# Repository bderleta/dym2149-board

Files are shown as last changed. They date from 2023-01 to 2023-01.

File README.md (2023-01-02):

# dym2149-board
Dual YM2149 synth board design using retro technology (THT elements, DIP packages)

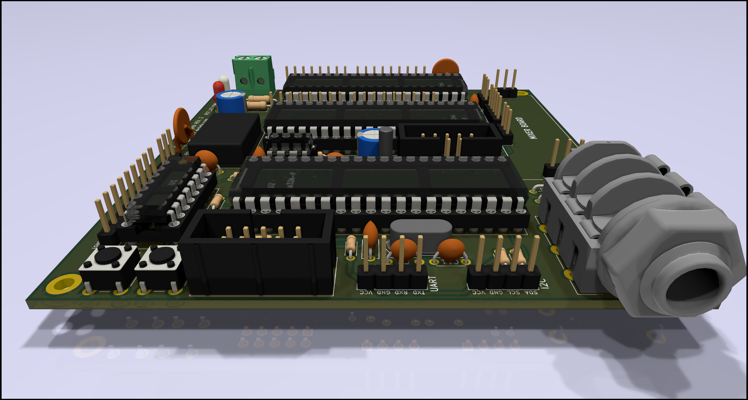
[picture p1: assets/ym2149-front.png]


An application of ATMega32 8-bit MCU in PDIP package capable of driving two of YM2149 PSG chips. [Reference firmware](https://github.com/bderleta/dym2149-firmware-ph) is just passing packets to selected PSG, but possibilities are very wide.

# Revision 2 changes

-  `U595_SRCLR` and `U595_RCLK` are swapped, to put `RCLK` to pin `OC0`, allowing to strobe `RCLK` pin from Timer0 compare output. This way the onboard shift register can be driven fully asynchronously, as `SRCLK` and `SER` are driven by SPI peripheral. Attention must be paid when SRAM/flash is used in the application.
- `YM1_BC1` and `YM1_SEL` are swapped, to put `YM1_SEL` to pin `OC1B`, allowing to switch `YM1_SEL` pin from Timer1 compare output. `YM2_SEL` is already on `OC1A` in all revisions. As `SEL` pin divides internal PSG clock by 2, in theory it should also divide an output frequency by 2, leading to sound an octave lower than before, although it has to be tested if any interesting effects can be obtained this way.
- Placement of I2C and UART ports has been slightly changed.

# Features

- ATMega32 MCU in PDIP package, clocked with external 16MHz crystal oscillator
- 10 pin ISP (KANDA) and JTAG ports 
- Two sockets for YM2149 PSG chips, independent control lines, shared data/address line
- DIP8 socket for SPI flash/RAM
- 595 shift register with 8 pin output header, controlled via SPI, for debugging/driving peripherals
- Headers for both I/O ports of each PSG
- 32768 Hz secondary oscillator for CPU Timer2
- Requires DIP8/DIP14 CXO for clocking YM chips
- Revision 1a/2 design features separate [mixer board](https://github.com/bderleta/dym2149-oric-mixer) to enable developing various output stages (different chip/channel assignments, active opamp stage, etc)

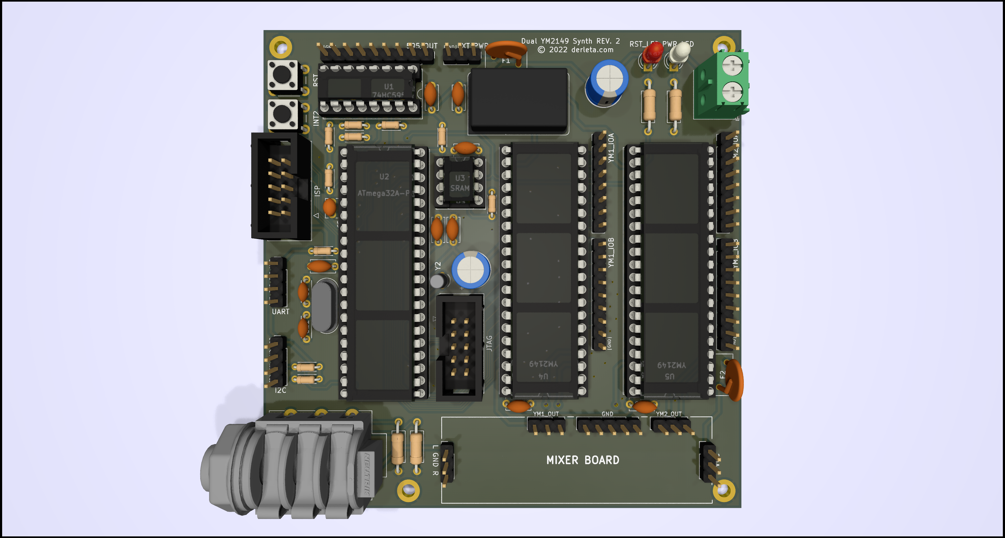
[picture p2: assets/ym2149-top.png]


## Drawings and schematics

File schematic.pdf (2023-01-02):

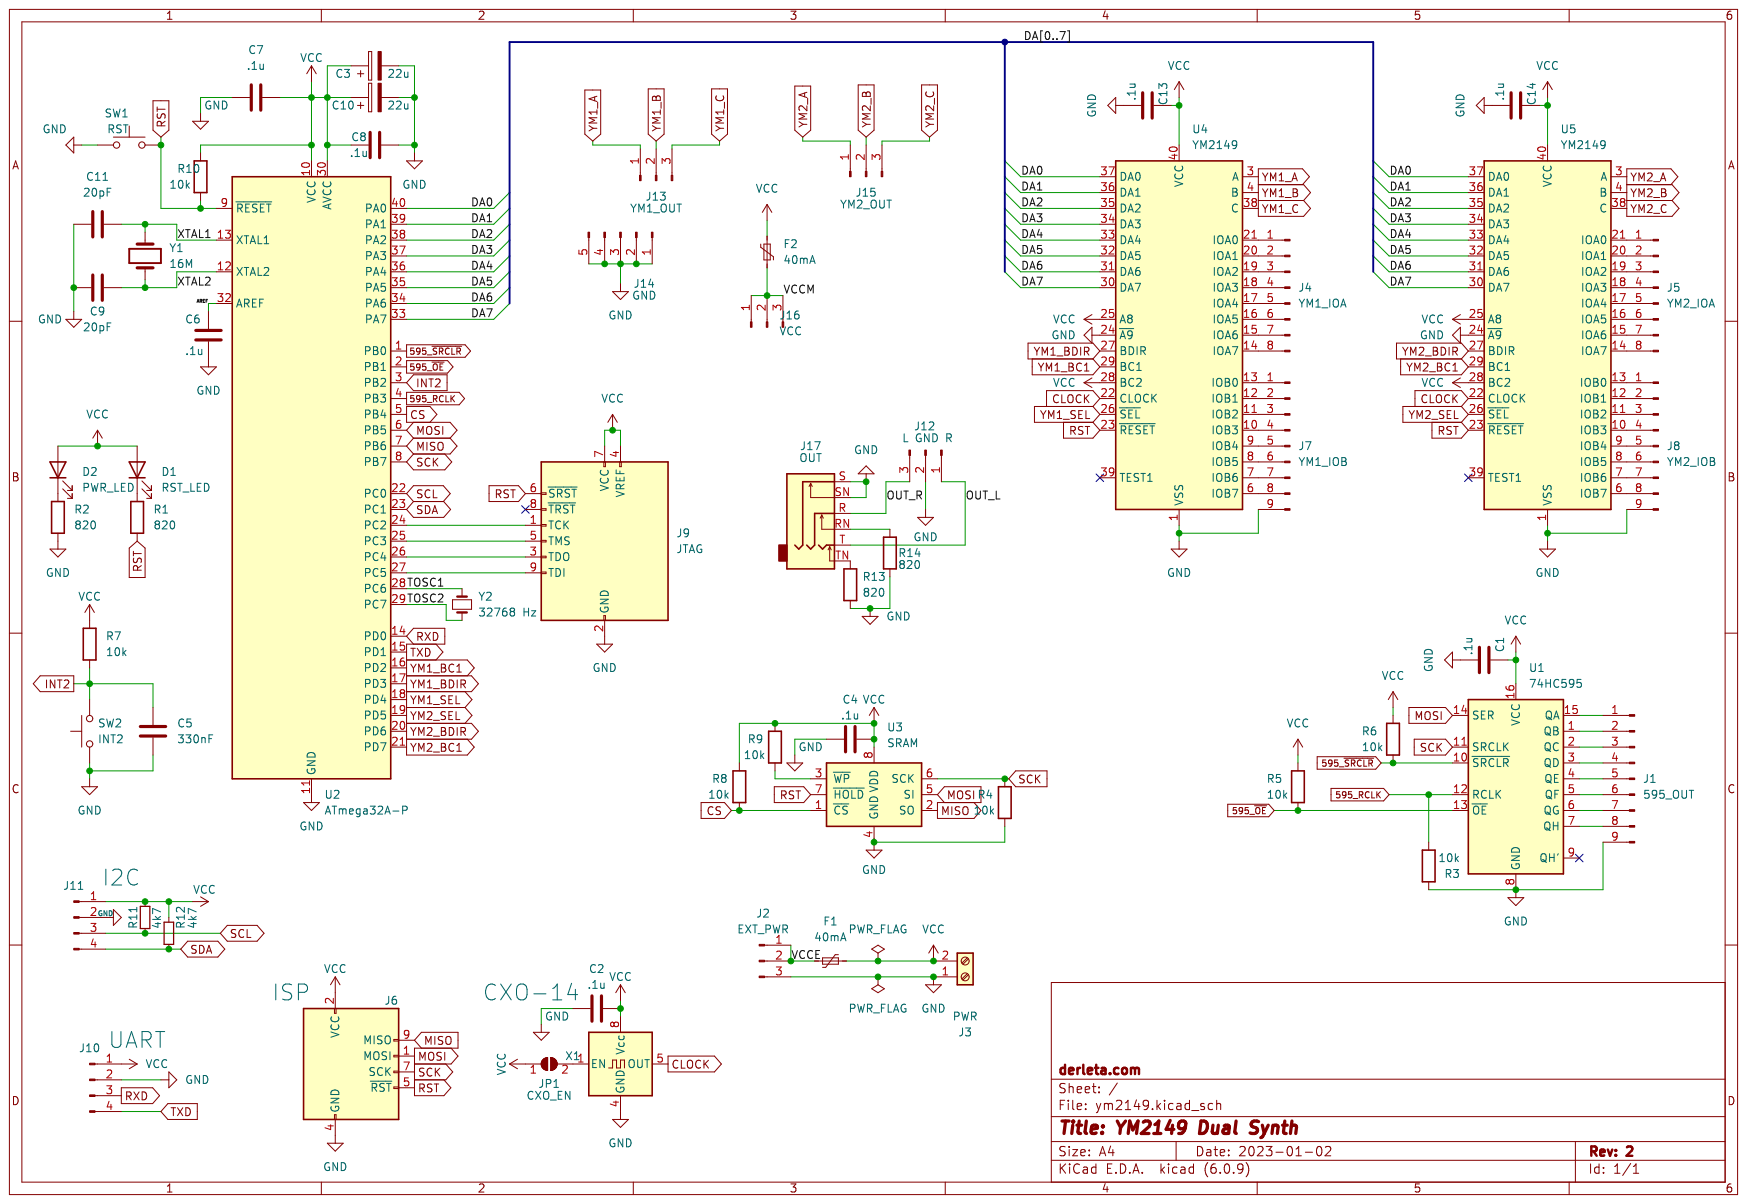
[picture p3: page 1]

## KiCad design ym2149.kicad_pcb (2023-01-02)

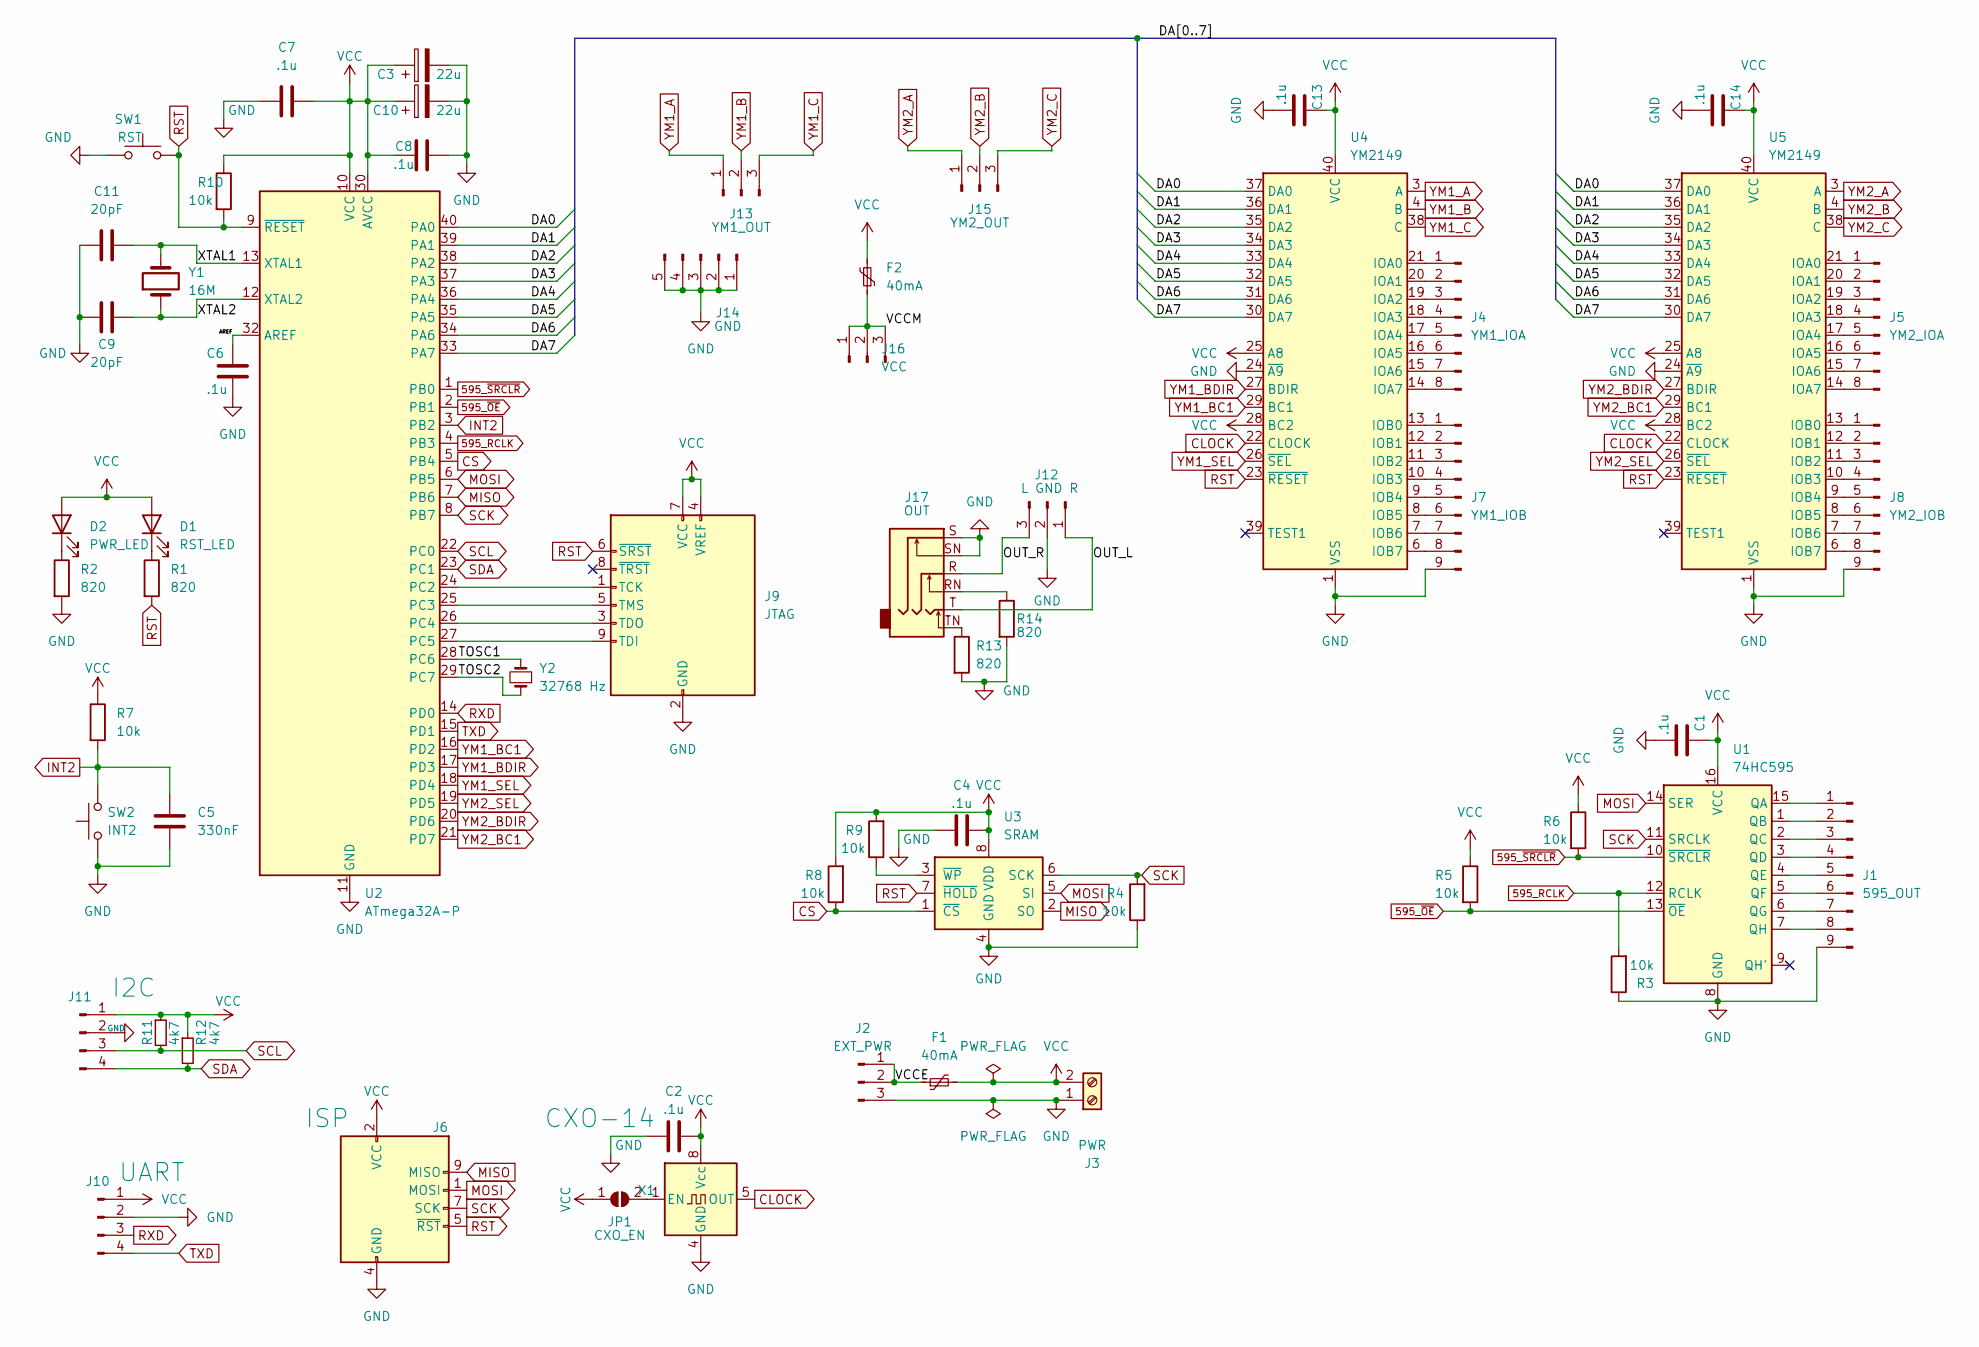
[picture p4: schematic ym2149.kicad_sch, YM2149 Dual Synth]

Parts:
C1, C2, C4, C6, C7, C8, C13, C14: .1u; C_Disc_D5.0mm_W2.5mm_P5.00mm
C3, C10: 22u; CP_Radial_D7.5mm_P2.50mm
C5: 330nF; C_Disc_D3.8mm_W2.6mm_P2.50mm
C9, C11: 20pF; C_Disc_D4.3mm_W1.9mm_P5.00mm
D1: RST_LED; LED_D3.0mm
D2: PWR_LED; LED_D3.0mm
F1, F2: 40mA; Fuse_BelFuse_0ZRE0005FF_L8.3mm_W3.8mm
J1: 595_OUT; PinHeader_1x09_P2.54mm_Vertical
J2: EXT_PWR; PinHeader_1x03_P2.54mm_Vertical
J3: PWR; TerminalBlock_Phoenix_PT-1,5-2-5.0-H_1x02_P5.00mm_Horizontal
J4: YM1_IOA; PinHeader_1x08_P2.54mm_Vertical
J5: YM2_IOA; PinHeader_1x08_P2.54mm_Vertical
J6: ISP; IDC-Header_2x05_P2.54mm_Vertical
J7: YM1_IOB; PinHeader_1x09_P2.54mm_Vertical
J8: YM2_IOB; PinHeader_1x09_P2.54mm_Vertical
J9: JTAG; IDC-Header_2x05_P2.54mm_Vertical
J10: UART; PinHeader_1x04_P2.54mm_Vertical
J11: I2C; PinHeader_1x04_P2.54mm_Vertical
J12: L GND R; PinHeader_1x03_P2.54mm_Vertical
J13: YM1_OUT; PinHeader_1x03_P2.54mm_Vertical
J14: GND; PinHeader_1x05_P2.54mm_Vertical
J15: YM2_OUT; PinHeader_1x03_P2.54mm_Vertical
J16: VCC; PinHeader_1x03_P2.54mm_Vertical
J17: OUT; Jack_6.35mm_Neutrik_NMJ6HFD2-AU_Horizontal
JP1: CXO_EN; SolderJumper-2_P1.3mm_Open_RoundedPad1.0x1.5mm
R1, R2, R13, R14: 820; R_Axial_DIN0207_L6.3mm_D2.5mm_P10.16mm_Horizontal
R3, R4, R5, R6, R7, R8, R9, R10: 10k; R_Axial_DIN0204_L3.6mm_D1.6mm_P5.08mm_Horizontal
R11, R12: 4k7; R_Axial_DIN0204_L3.6mm_D1.6mm_P5.08mm_Horizontal
SW1: RST; SW_PUSH_6mm
SW2: INT2; SW_PUSH_6mm
U1: 74HC595; DIP-16_W7.62mm_Socket
U2: ATmega32A-P; DIP-40_W15.24mm_Socket
U3: SRAM; DIP-8_W7.62mm_Socket
U4, U5: YM2149; DIP-40_W15.24mm_Socket
X1: CXO-14; CXO-14-8
Y1: 16M; Crystal_HC49-4H_Vertical
Y2: 32768 Hz; Crystal_AT310_D3.0mm_L10.0mm_Vertical

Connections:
595_RCLK: R3.2, U1.12 (RCLK), U2.4 (PB3)
595_~OE: R5.2, U1.13 (~OE), U2.2 (PB1)
595_~SRCLR: R6.2, U1.10 (~SRCLR), U2.1 (PB0)
/AREF: C6.2, U2.32 (AREF)
/DA0: U2.40 (PA0), U4.37 (DA0), U5.37 (DA0)
/DA1: U2.39 (PA1), U4.36 (DA1), U5.36 (DA1)
/DA2: U2.38 (PA2), U4.35 (DA2), U5.35 (DA2)
/DA3: U2.37 (PA3), U4.34 (DA3), U5.34 (DA3)
/DA4: U2.36 (PA4), U4.33 (DA4), U5.33 (DA4)
/DA5: U2.35 (PA5), U4.32 (DA5), U5.32 (DA5)
/DA6: U2.34 (PA6), U4.31 (DA6), U5.31 (DA6)
/DA7: U2.33 (PA7), U4.30 (DA7), U5.30 (DA7)
/OUT_L: J12.1, J17.T
/OUT_R: J12.3, J17.R
/TOSC1: U2.28 (PC6), Y2.2
/TOSC2: U2.29 (PC7), Y2.1
/VCCE: F1.1, J2.1, J2.2
/VCCM: F2.1, J16.1, J16.2, J16.3
/XTAL1: C11.2, U2.13 (XTAL1), Y1.2
/XTAL2: C9.2, U2.12 (XTAL2), Y1.1
CLOCK: U4.22 (CLOCK), U5.22 (CLOCK), X1.5 (OUT)
CS: R8.1, U2.5 (PB4), U3.1 (~CS)
GND: C1.1, C2.2, C3.2, C4.2, C5.2, C6.1, C7.2, C8.2, C9.1, C10.2, C11.1, C13.1, C14.1, J1.9, J2.3, J3.1, J6.4 (GND), J6.6 (GND), J6.8 (GND), J6.10 (GND), J7.9, J8.9, J9.2 (GND), J9.10 (GND), J10.2, J11.2, J12.2, J14.1, J14.2, J14.3, J14.4, J14.5, J17.S, J17.SN, R2.2, R3.1, R4.1, R13.2, R14.2, SW1.1, SW2.1, U1.8 (GND), U2.11 (GND), U2.31 (GND), U3.4 (GND), U4.1 (VSS), U4.24 (~A9), U5.1 (VSS), U5.24 (~A9), X1.4 (GND); also elsewhere on the board
INT2: C5.1, R7.2, SW2.2, U2.3 (PB2)
MISO: J6.9 (MISO), U2.7 (PB6), U3.2 (SO)
MOSI: J6.1 (MOSI), U1.14 (SER), U2.6 (PB5), U3.5 (SI)
unnamed: D1.1 (K), R1.1
unnamed: D2.1 (K), R2.1
unnamed: J1.1, U1.15 (QA)
unnamed: J1.2, U1.1 (QB)
unnamed: J1.3, U1.2 (QC)
unnamed: J1.4, U1.3 (QD)
unnamed: J1.5, U1.4 (QE)
unnamed: J1.6, U1.5 (QF)
unnamed: J1.7, U1.6 (QG)
unnamed: J1.8, U1.7 (QH)
unnamed: J4.1, U4.21 (IOA0)
unnamed: J4.2, U4.20 (IOA1)
unnamed: J4.3, U4.19 (IOA2)
unnamed: J4.4, U4.18 (IOA3)
unnamed: J4.5, U4.17 (IOA4)
unnamed: J4.6, U4.16 (IOA5)
unnamed: J4.7, U4.15 (IOA6)
unnamed: J4.8, U4.14 (IOA7)
unnamed: J5.1, U5.21 (IOA0)
unnamed: J5.2, U5.20 (IOA1)
unnamed: J5.3, U5.19 (IOA2)
unnamed: J5.4, U5.18 (IOA3)
unnamed: J5.5, U5.17 (IOA4)
unnamed: J5.6, U5.16 (IOA5)
unnamed: J5.7, U5.15 (IOA6)
unnamed: J5.8, U5.14 (IOA7)
unnamed: J7.1, U4.13 (IOB0)
unnamed: J7.2, U4.12 (IOB1)
unnamed: J7.3, U4.11 (IOB2)
unnamed: J7.4, U4.10 (IOB3)
unnamed: J7.5, U4.9 (IOB4)
unnamed: J7.6, U4.8 (IOB5)
unnamed: J7.7, U4.7 (IOB6)
unnamed: J7.8, U4.6 (IOB7)
unnamed: J8.1, U5.13 (IOB0)
unnamed: J8.2, U5.12 (IOB1)
unnamed: J8.3, U5.11 (IOB2)
unnamed: J8.4, U5.10 (IOB3)
unnamed: J8.5, U5.9 (IOB4)
unnamed: J8.6, U5.8 (IOB5)
unnamed: J8.7, U5.7 (IOB6)
unnamed: J8.8, U5.6 (IOB7)
unnamed: J9.1 (TCK), U2.24 (PC2)
unnamed: J9.3 (TDO), U2.26 (PC4)
unnamed: J9.5 (TMS), U2.25 (PC3)
unnamed: J9.9 (TDI), U2.27 (PC5)
unnamed: J17.RN, R14.1
unnamed: J17.TN, R13.1
unnamed: JP1.2 (B), X1.1 (EN)
unnamed: R9.1, U3.3 (~WP)
RST: J6.5 (~RST), J9.6 (~SRST), R1.2, R10.2, SW1.2, U2.9 (~RESET), U3.7 (~HOLD), U4.23 (~RESET), U5.23 (~RESET)
RXD: J10.3, U2.14 (PD0)
SCK: J6.7 (SCK), R4.2, U1.11 (SRCLK), U2.8 (PB7), U3.6 (SCK)
SCL: J11.3, R11.2, U2.22 (PC0)
SDA: J11.4, R12.2, U2.23 (PC1)
TXD: J10.4, U2.15 (PD1)
VCC: C1.2, C2.1, C3.1, C4.1, C7.1, C8.1, C10.1, C13.2, C14.2, D1.2 (A), D2.2 (A), F1.2, F2.2, J3.2, J6.2 (VCC), J9.4 (VREF), J9.7 (VCC), J10.1, J11.1, JP1.1 (A), R5.1, R6.1, R7.1, R8.2, R9.2, R10.1, R11.1, R12.1, U1.16 (VCC), U2.10 (VCC), U2.30 (AVCC), U3.8 (VDD), U4.25 (A8), U4.28 (BC2), U4.40 (VCC), U5.25 (A8), U5.28 (BC2), U5.40 (VCC), X1.8 (Vcc)
YM1_A: J13.1, U4.3 (A)
YM1_B: J13.2, U4.4 (B)
YM1_BC1: U2.16 (PD2), U4.29 (BC1)
YM1_BDIR: U2.17 (PD3), U4.27 (BDIR)
YM1_C: J13.3, U4.38 (C)
YM1_SEL: U2.18 (PD4), U4.26 (~SEL)
YM2_A: J15.1, U5.3 (A)
YM2_B: J15.2, U5.4 (B)
YM2_BC1: U2.21 (PD7), U5.29 (BC1)
YM2_BDIR: U2.20 (PD6), U5.27 (BDIR)
YM2_C: J15.3, U5.38 (C)
YM2_SEL: U2.19 (PD5), U5.26 (~SEL)

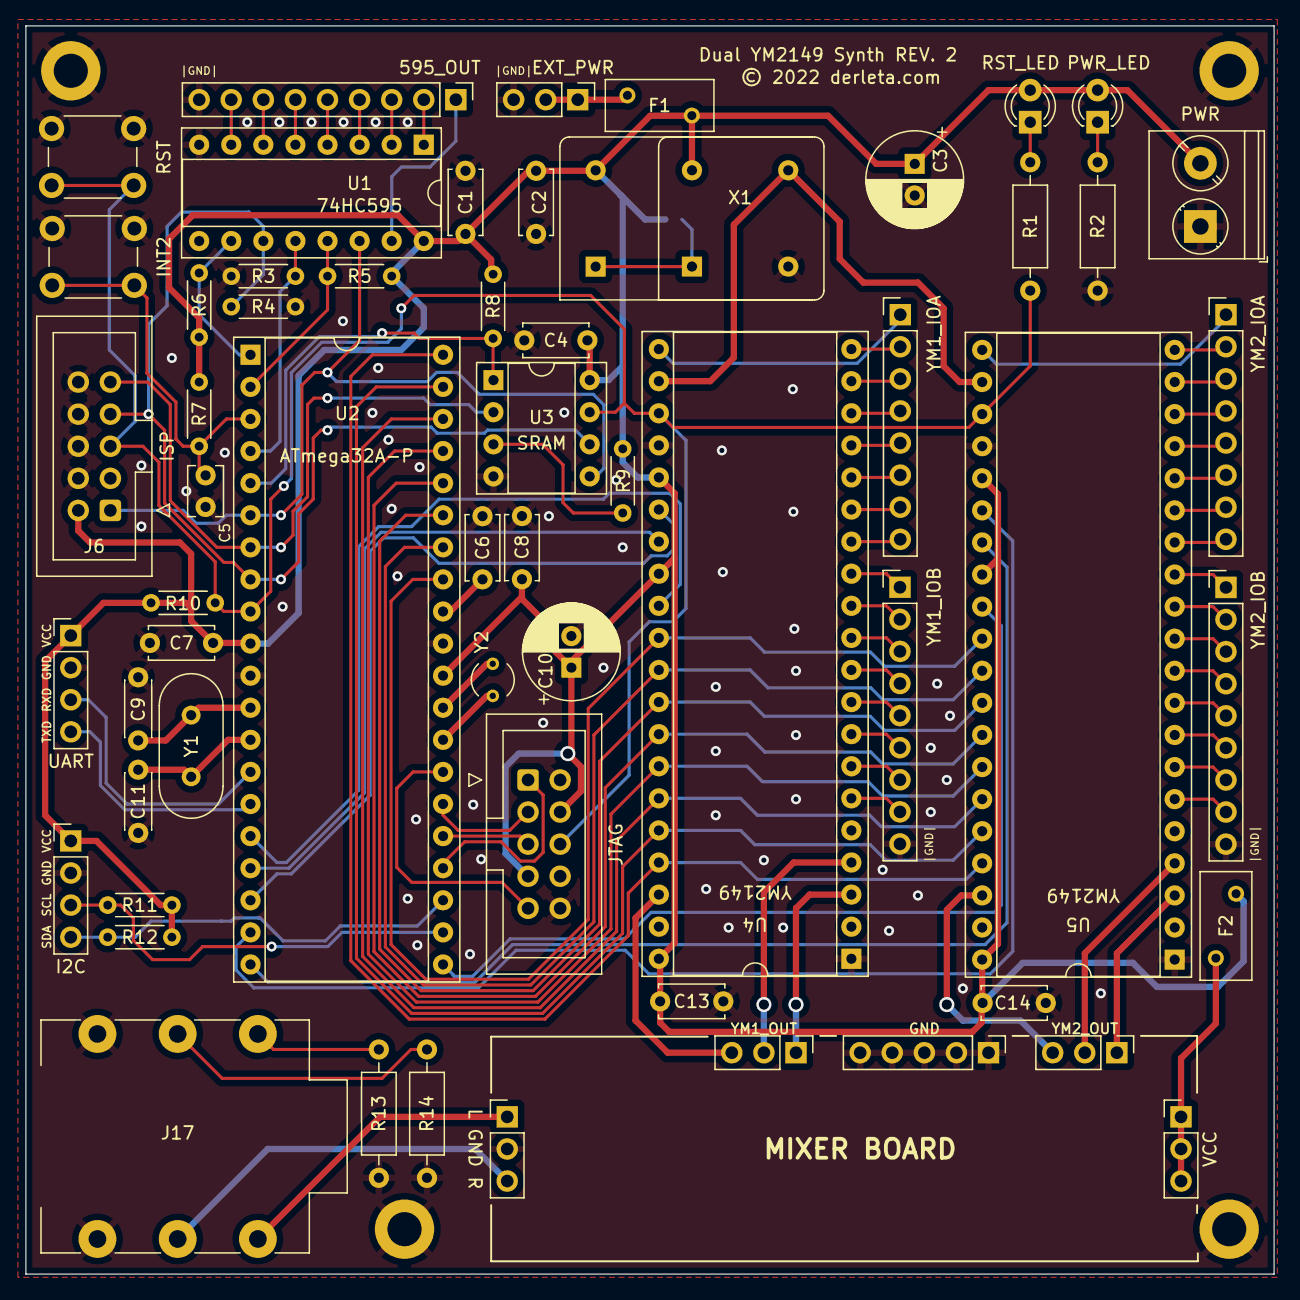
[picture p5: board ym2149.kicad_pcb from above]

Board: 2 copper layers, 98.8 x 98.8 mm, 63 parts (1 on the bottom side), 95 nets.

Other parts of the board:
MH1, MH2, MH3, MH4: MountingHole_2.7mm_M2.5_DIN965_Pad

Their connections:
GND: MH1.1, MH2.1, MH3.1, MH4.1; also elsewhere on the board

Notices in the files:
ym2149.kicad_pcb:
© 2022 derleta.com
